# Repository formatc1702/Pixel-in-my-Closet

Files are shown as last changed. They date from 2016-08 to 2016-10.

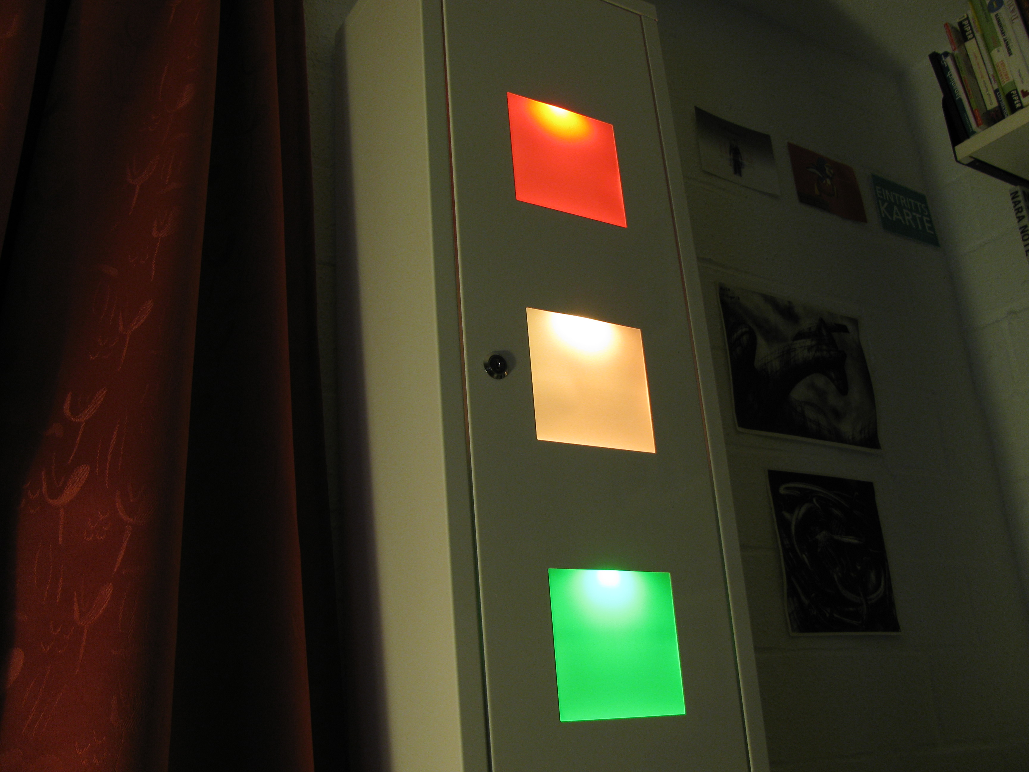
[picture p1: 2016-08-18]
Docs/Photos/IMG_2092.JPG

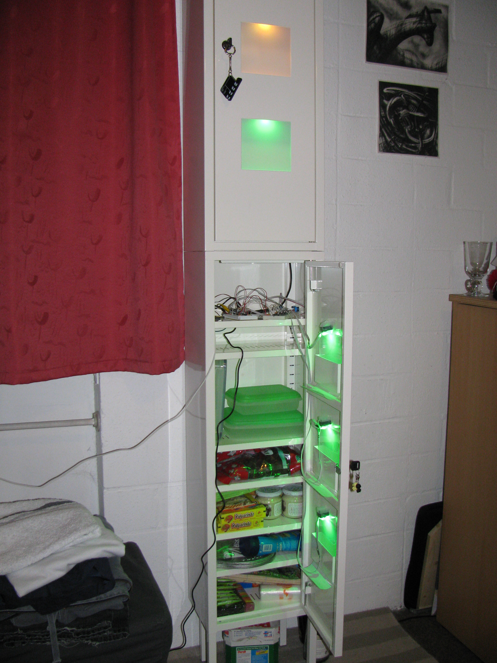
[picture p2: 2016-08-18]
Docs/Photos/IMG_2070.JPG

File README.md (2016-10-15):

#Pixel in my Closet v1

##Description
Music + Arduino + IKEA.
Using six 3W RGB LEDs inside an IKEA PS CD cabinet to light up in reaction to the music attached through a 3.5mm stereo cable. It is combined with the receiver of an old iPod RF remote used to change visualizations and color schemes.
See the YouTube video [here](https://www.youtube.com/watch?v=BKGa15BCBik).

##Directory structure
- **Arduino** contains the firmware. It is a quick&dirty hack and has not been cleaned up.
- **EAGLE** contains the schematic and PCB design files for the project.

##Where to get parts
- [The 3W RGB LED](http://www.dx.com/p/3w-led-emitter-on-star-multicolored-rgb-4530)

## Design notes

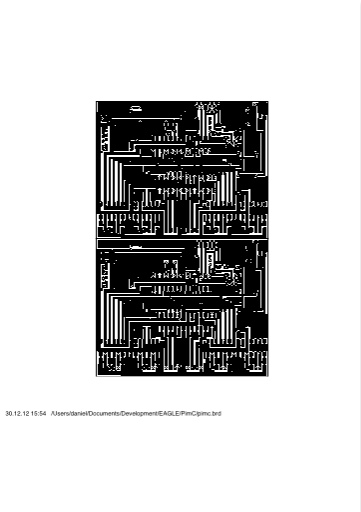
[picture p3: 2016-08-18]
Schematics/PimC_Final/PCB2X.pages/QuickLook/Thumbnail.jpg

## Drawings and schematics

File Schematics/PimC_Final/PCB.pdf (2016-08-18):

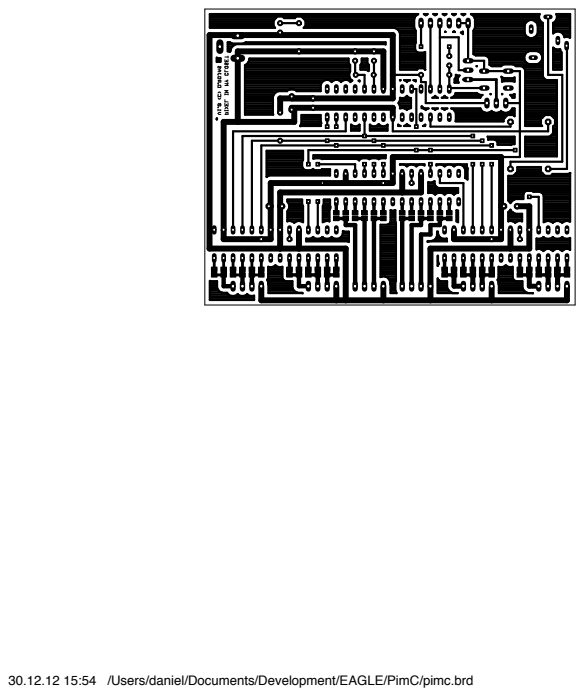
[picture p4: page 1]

30.12.12 15:54 /Users/daniel/Documents/Development/EAGLE/PimC/pimc.brd

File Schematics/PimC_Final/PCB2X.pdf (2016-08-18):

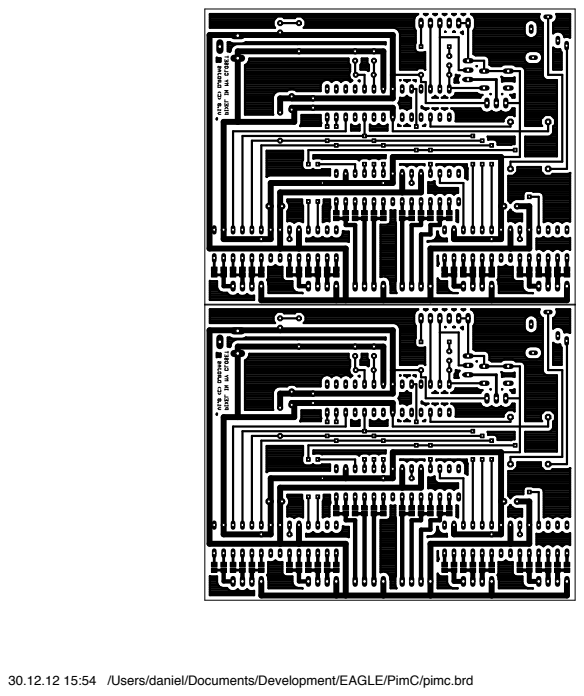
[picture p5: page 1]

30.12.12 15:54 /Users/daniel/Documents/Development/EAGLE/PimC/pimc.brd

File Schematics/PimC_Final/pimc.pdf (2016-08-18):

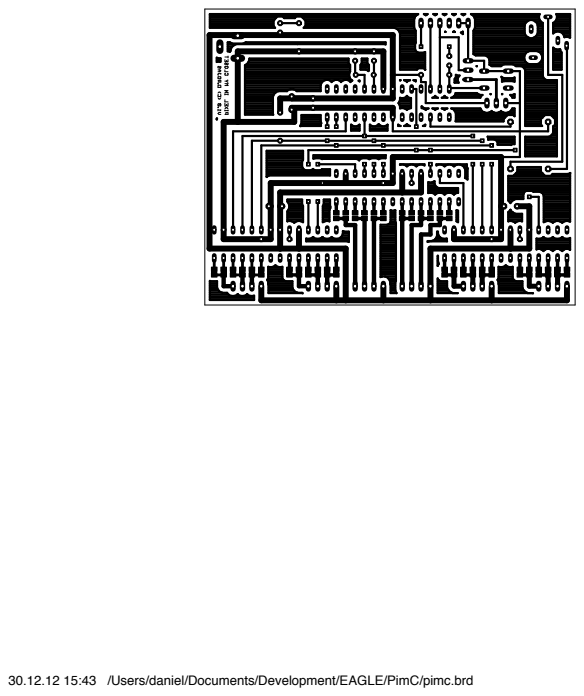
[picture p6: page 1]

30.12.12 15:43 /Users/daniel/Documents/Development/EAGLE/PimC/pimc.brd

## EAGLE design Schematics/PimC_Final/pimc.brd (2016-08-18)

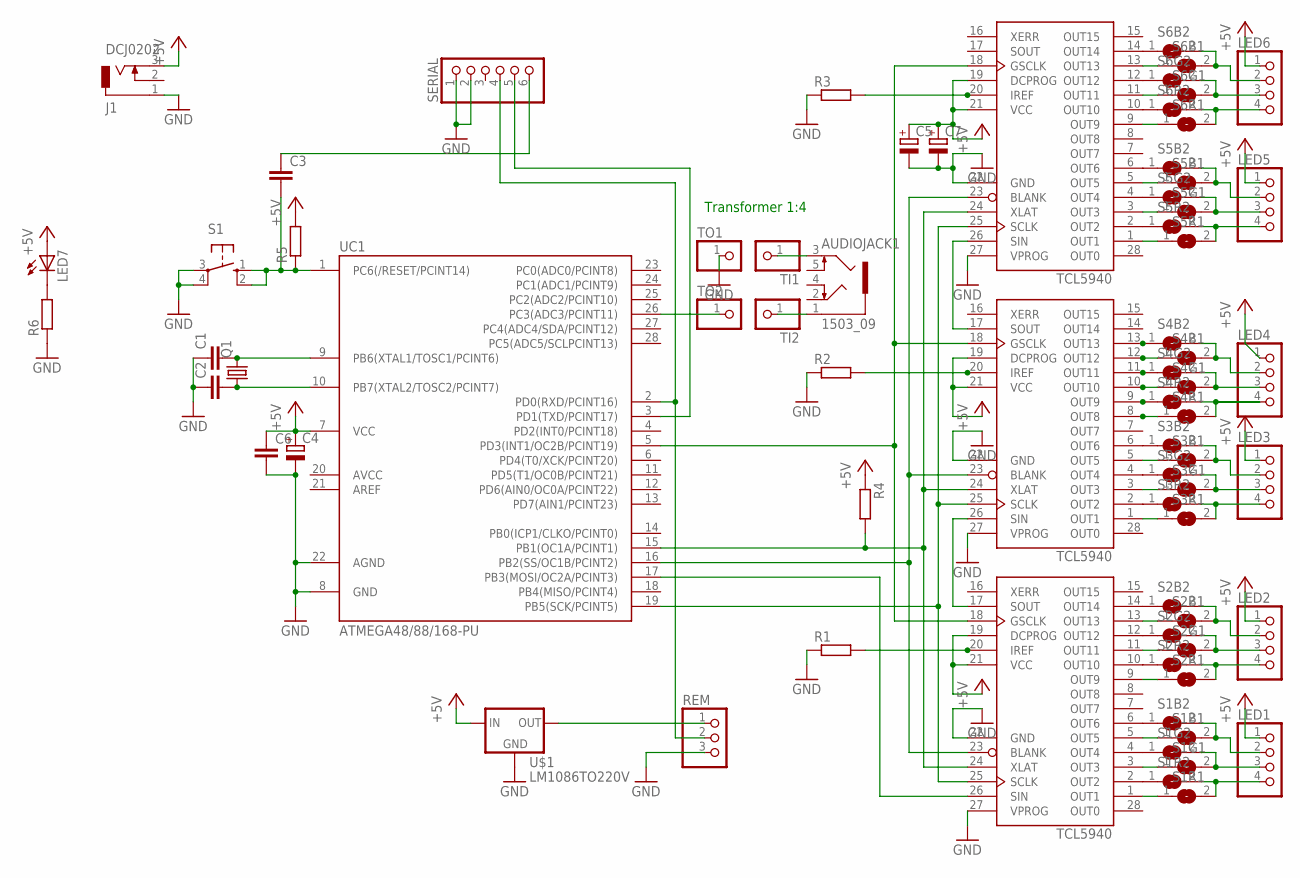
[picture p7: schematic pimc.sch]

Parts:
AUDIOJACK1: 1503_09
C1, C2, C3, C6: C-EU025-025X050; C025-025X050
C4, C5, C7: CPOL-EUE3.5-8; E3,5-8
DRV1, DRV2, DRV3: TCL5940; DIP28
J1: DCJ0202
LED1, LED2, LED3, LED4, LED5, LED6: PINHD-1X4; 1X04
LED7: LED5MM
Q1: CRYSTALHC49S; HC49/S
R1, R2, R3, R4, R5, R6: R-EU_0204/7; 0204/7
REM: PINHD-1X3; 1X03
S1: 10-XX; B3F-10XX
S1B1, S1B2, S1G1, S1G2, S1R1, S1R2, S2B1, S2B2, S2G1, S2G2, S2R1, S2R2, S3B1, S3B2, S3G1, S3G2, S3R1, S3R2, S4B1, S4B2, S4G1, S4G2, S4R1, S4R2, S5B1, S5B2, S5G1, S5G2, S5R1, S5R2, S6B1, S6B2, S6G1, S6G2, S6R1, S6R2: SJ
SERIAL: PINHD-1X6; 1X06
TI1, TI2: PINHD-1X1; 1X01
TO1, TO2: PINHD-1X1; 1X01
U$1: LM1086TO220V; TO220S
UC1: ATMEGA48/88/168-PU; DIL28-3

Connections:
+5V: C4.+, C5.+, C6.1, C7.+, DRV1.19 (DCPROG), DRV1.21 (VCC), DRV2.19 (DCPROG), DRV2.21 (VCC), DRV3.19 (DCPROG), DRV3.21 (VCC), J1.3, LED1.1, LED2.1, LED3.1, LED4.1, LED5.1, LED6.1, LED7.A, R4.1, R5.2, U$1.3 (IN), UC1.7 (VCC)
GND: C1.1, C2.1, C4.-, C5.-, C6.2, C7.-, DRV1.22 (GND), DRV1.27 (VPROG), DRV2.22 (GND), DRV2.27 (VPROG), DRV3.22 (GND), DRV3.27 (VPROG), J1.1, R1.1, R2.1, R3.1, R6.1, REM.3, S1.3, S1.4 (P1), SERIAL.1, SERIAL.2, TO1.1, U$1.1 (GND), UC1.8 (GND), UC1.22 (AGND)
unnamed: DRV1.14 (OUT14), S2B2.1
unnamed: DRV1.12 (OUT12), S2G2.1
unnamed: DRV1.10 (OUT10), S2R2.1
unnamed: DRV1.2 (OUT2), S1R2.1
unnamed: DRV1.4 (OUT4), S1G2.1
unnamed: DRV1.6 (OUT6), S1B2.1
unnamed: DRV1.13 (OUT13), S2B1.1
unnamed: DRV1.11 (OUT11), S2G1.1
unnamed: DRV1.9 (OUT9), S2R1.1
unnamed: DRV1.5 (OUT5), S1B1.1
unnamed: DRV1.3 (OUT3), S1G1.1
unnamed: DRV1.1 (OUT1), S1R1.1
unnamed: LED2.2, S2B1.2, S2B2.2
unnamed: LED2.3, S2G1.2, S2G2.2
unnamed: LED2.4, S2R1.2, S2R2.2
unnamed: LED1.2, S1B1.2, S1B2.2
unnamed: LED1.3, S1G1.2, S1G2.2
unnamed: LED1.4, S1R1.2, S1R2.2
unnamed: DRV2.8 (OUT8), S4R1.1
unnamed: DRV2.10 (OUT10), S4G1.1
unnamed: DRV2.12 (OUT12), S4B1.1
unnamed: DRV2.5 (OUT5), S3B1.1
unnamed: DRV2.3 (OUT3), S3G1.1
unnamed: DRV2.1 (OUT1), S3R1.1
unnamed: LED4.4, S4R1.2, S4R2.2
unnamed: LED4.3, S4G1.2, S4G2.2
unnamed: LED4.2, S4B1.2, S4B2.2
unnamed: LED3.2, S3B1.2, S3B2.2
unnamed: LED3.3, S3G1.2, S3G2.2
unnamed: LED3.4, S3R1.2, S3R2.2
unnamed: DRV2.9 (OUT9), S4R2.1
unnamed: DRV2.11 (OUT11), S4G2.1
unnamed: DRV2.13 (OUT13), S4B2.1
unnamed: DRV2.2 (OUT2), S3R2.1
unnamed: DRV2.4 (OUT4), S3G2.1
unnamed: DRV2.6 (OUT6), S3B2.1
unnamed: DRV3.13 (OUT13), S6B1.1
unnamed: DRV3.11 (OUT11), S6G1.1
unnamed: DRV3.9 (OUT9), S6R1.1
unnamed: DRV3.5 (OUT5), S5B1.1
unnamed: DRV3.3 (OUT3), S5G1.1
unnamed: DRV3.1 (OUT1), S5R1.1
unnamed: LED6.2, S6B1.2, S6B2.2
unnamed: LED6.3, S6G1.2, S6G2.2
unnamed: LED6.4, S6R1.2, S6R2.2
unnamed: LED5.2, S5B1.2, S5B2.2
unnamed: LED5.3, S5G1.2, S5G2.2
unnamed: LED5.4, S5R1.2, S5R2.2
unnamed: DRV3.14 (OUT14), S6B2.1
unnamed: DRV3.12 (OUT12), S6G2.1
unnamed: DRV3.10 (OUT10), S6R2.1
unnamed: DRV3.2 (OUT2), S5R2.1
unnamed: DRV3.4 (OUT4), S5G2.1
unnamed: DRV3.6 (OUT6), S5B2.1
unnamed: DRV1.17 (SOUT), DRV2.26 (SIN)
unnamed: DRV2.17 (SOUT), DRV3.26 (SIN)
unnamed: DRV1.26 (SIN), UC1.17 (PB3(MOSI/OC2A/PCINT3))
unnamed: DRV1.25 (SCLK), DRV2.25 (SCLK), DRV3.25 (SCLK), UC1.19 (PB5(SCK/PCINT5))
unnamed: DRV1.24 (XLAT), DRV2.24 (XLAT), DRV3.24 (XLAT), R4.2, UC1.15 (PB1(OC1A/PCINT1))
unnamed: DRV1.23 (BLANK), DRV2.23 (BLANK), DRV3.23 (BLANK), UC1.16 (PB2(SS/OC1B/PCINT2))
unnamed: DRV3.20 (IREF), R3.2
unnamed: DRV2.20 (IREF), R2.2
unnamed: DRV1.20 (IREF), R1.2
unnamed: DRV1.18 (GSCLK), DRV2.18 (GSCLK), DRV3.18 (GSCLK), UC1.5 (PD3(INT1/OC2B/PCINT19))
unnamed: C1.2, Q1.2, UC1.9 (PB6(XTAL1/TOSC1/PCINT6))
unnamed: C2.2, Q1.1, UC1.10 (PB7(XTAL2/TOSC2/PCINT7))
unnamed: AUDIOJACK1.1, TI2.1
unnamed: AUDIOJACK1.3, TI1.1
unnamed: LED7.K (C), R6.2
unnamed: REM.2, SERIAL.4, UC1.2 (PD0(RXD/PCINT16))
unnamed: SERIAL.5, UC1.3 (PD1(TXD/PCINT17))
unnamed: C3.2, R5.1, S1.1 (S), S1.2 (S1), UC1.1 (PC6(/RESET/PCINT14))
unnamed: C3.1, SERIAL.6
unnamed: REM.1, U$1.2 (OUT)
unnamed: TO2.1, UC1.26 (PC3(ADC3/PCINT11))

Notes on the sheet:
Transformer 1:4

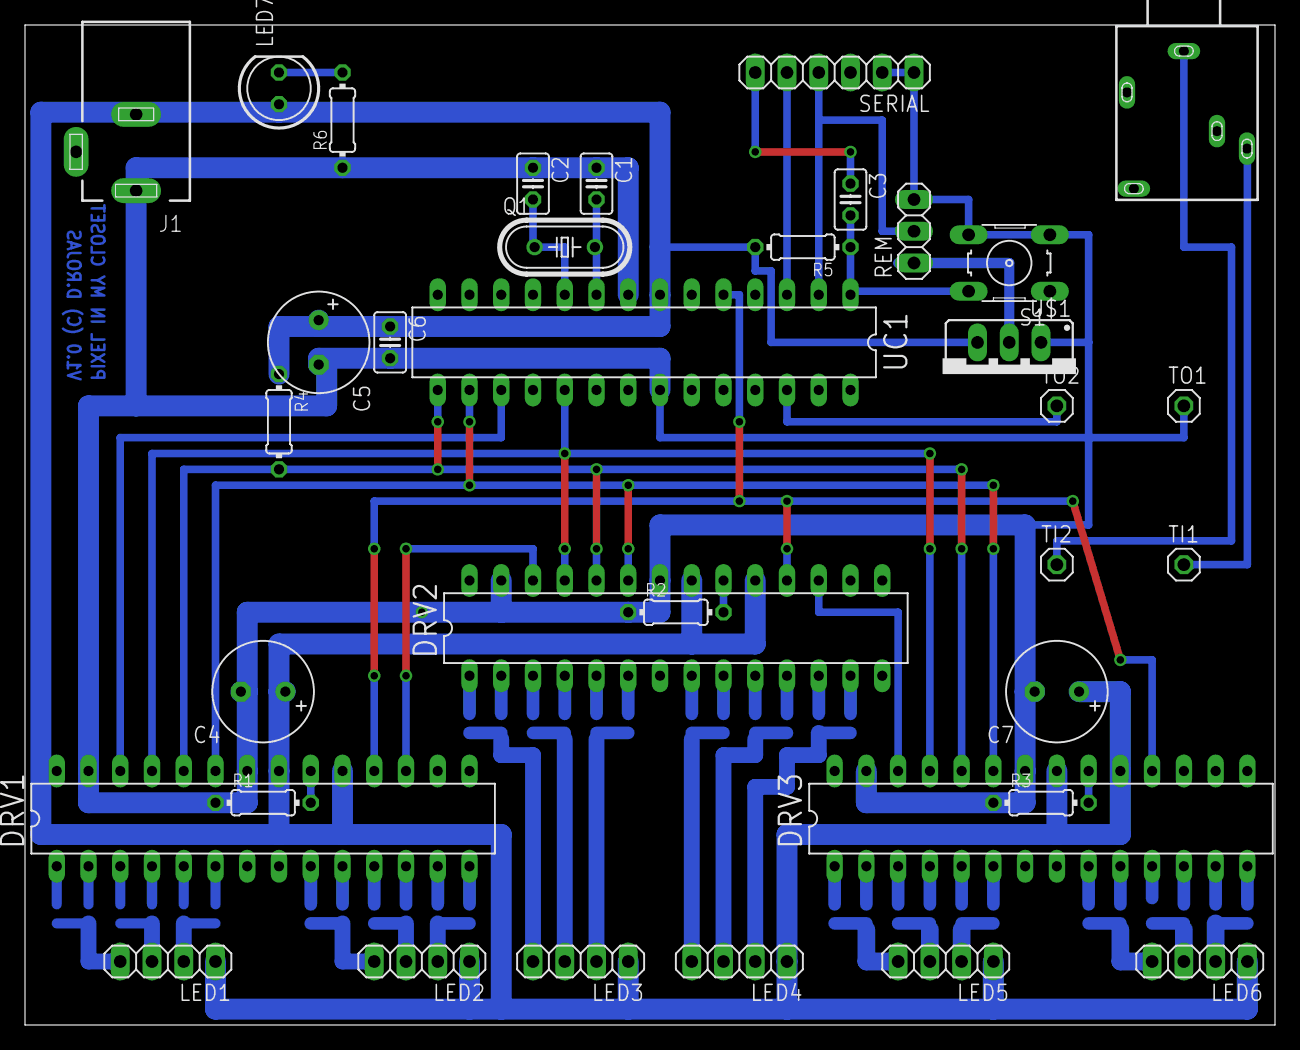
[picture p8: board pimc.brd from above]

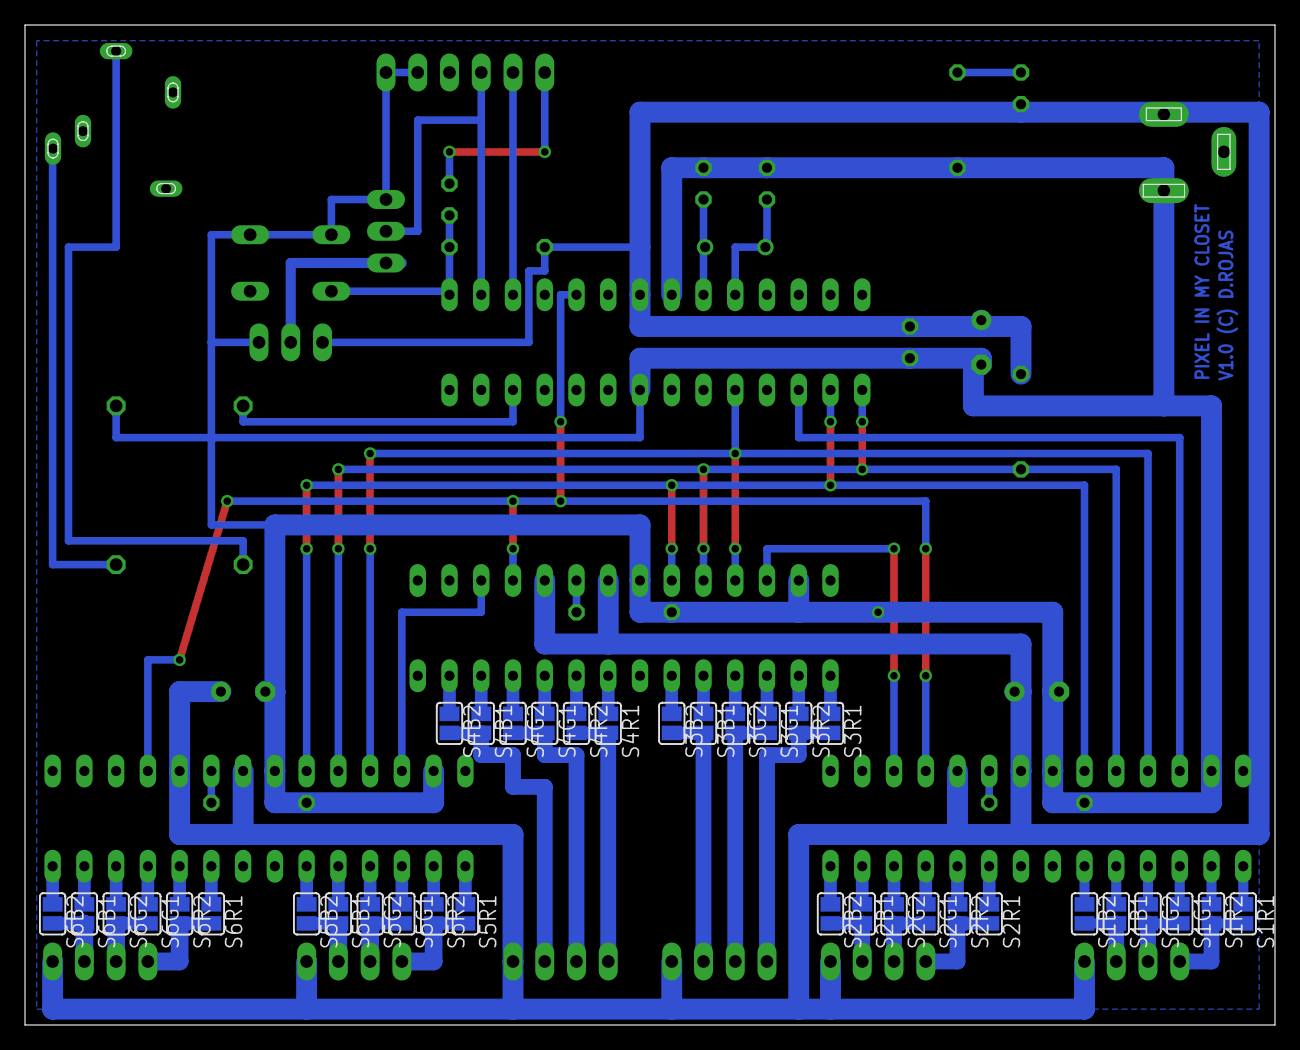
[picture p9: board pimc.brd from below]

Board: 2 copper layers, 100.0 x 80.0 mm, 71 parts (36 on the bottom side), 77 nets.

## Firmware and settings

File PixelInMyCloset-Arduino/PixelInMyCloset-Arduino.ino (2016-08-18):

#include <Wire.h>
#include "lib/Tlc5940/Tlc5940.h"
//#define max6955 B1100000
//#define max6956 B1000000

// MODE STUFF ***********************************************************

int CurrentMode=0;
int CurrentTheme=4;
long NewModeTimer=0;
boolean PoweredOn=true;

// GENERAL STUFF ******************************************************
int i;
long writemil=0;

// PIXEL STUFF ********************************************************

struct Pixel {
  byte red;
  byte green;
  byte blue;
};
struct Pixel BlackPixel={
  0,0,0};
struct Pixel RedPixel={
  255,0,0};
struct Pixel GreenPixel={
  0,255,0};
struct Pixel BluePixel={
  0,0,255};
struct Pixel YellowPixel={
  255,255,0};
struct Pixel CyanPixel={
  0,255,255};
struct Pixel MagentaPixel={
  255,0,255};
struct Pixel WhitePixel={
  255,255,255};
struct Pixel GreyPixel={
  128,128,128
};
struct Pixel OrangePixel={
  255,128,0};

struct PixelStream {
  struct Pixel pixels[6];
};
struct PixelStream BlackPixelStream={
  BlackPixel,BlackPixel,BlackPixel,BlackPixel,BlackPixel,BlackPixel};
struct PixelStream WhitePixelStream={
  WhitePixel,WhitePixel,WhitePixel,WhitePixel,WhitePixel,WhitePixel};

PixelStream toSend={
  0,0,0,0,0,0,0,0,0,0,0,0,0,0,0,0,0,0};
// REMOTE STUFF *********************************************************

#define RemoteREV  0x10
#define RemoteFWD  0x08
#define RemotePLAY 0x01
#define RemoteVDN  0x04
#define RemoteVUP  0x02

byte RemoteLastCommand=0x00;
boolean gotRemote=false;

// MODE 0 - Audiostuff***************************************************
int audioinputpin=3;

// Statuses
long cur=0;
int avgmax=0;
long smooth=0;
long expo=0;
int topbar=0;
int ledcount=0;
int dim;
byte maxbr=0;

// Cycle stuff
boolean cyclecolors=true;
int curcyclecolor=0;
int curcyclecolortemp1=0;
int curcyclecolortemp2=0;
int cyclered=0;
int cyclegreen=0;
int cycleblue=0;
long cycleinterval=16;
long lightfade=56;
long strongfade=170;

// Blip stuff
int curblipnumber=0;
byte curblipbrightness=0;
int curblipdir=0;
boolean curblipchange=false;
int blipcount=1;
int bliparray[]={
  0,0,0,0,0,0};
struct Pixel curblipcolor=BlackPixel;

// Timers
long smoothmil=0;
long ledmil=0;
long maxavgmil=0;
long topbarmil=0;
long cyclemil=0;
long maxbrmil=0;

int curmaxcounter=0;
int maxes[]={
  0,0,0,0,0,0,0,0,0,0};
//int tempmax=0;

// COLOR THEMES ******************************************************* 

struct PixelStream VUThemes[]={ // do not edit existing ones, only add new ones at the end
  {
    GreenPixel,GreenPixel,GreenPixel,GreenPixel,OrangePixel,RedPixel
  }
  ,
  {
    BluePixel,CyanPixel,GreenPixel,YellowPixel,RedPixel,MagentaPixel
  }
  ,
  { // WHY U NO WORK???
    GreenPixel,
    {
      64, 204,0    }
    ,
    {
      128,153,0    }
    ,
    {
      192,102,0    }
    ,
    {
      255,51, 0    }
    ,
    RedPixel
  }
  ,
  BlackPixelStream // all same

  ,
  BlackPixelStream // light fade
  ,
  BlackPixelStream // strong fade
  ,
  WhitePixelStream
};



/////////////////////////////////////////////////////////////////////

void setup()
{
  Tlc.init();
  delay(500);
  //randomSeed(millis());
  //  WireSetup_MAX6956_4bit();
  Serial.begin(19200);
  toSend=WhitePixelStream;
  WriteColors();
  delay(500);
  toSend=BlackPixelStream;
  WriteColors();
}

void loop()
{
  byte RemoteCommand=GetRemote();
  switch(RemoteCommand) {
  case RemotePLAY: 
    PoweredOn=!PoweredOn;
    //    if(!PoweredOn) {
    //      toSend=BlackPixelStream;
    //      WriteColors();
    //      delay(1000);
    //    }
    break;
  case RemoteFWD: 
    if(++CurrentMode>=6)
      CurrentMode=0;
    //    NewModeTimer=millis();
    maxbr=0;
    break;
  case RemoteREV: 
    if(--CurrentMode<0)
      CurrentMode=5;
    //    NewModeTimer=millis();
    maxbr=0;
    break;
  case RemoteVUP:
    switch(CurrentMode) {
    case 0:
    case 3:
    case 4:
    case 5:
      if(++CurrentTheme>=sizeof(VUThemes)/18)
        CurrentTheme=0;
      break;
    case 1:
      cyclecolors=!cyclecolors;
      break;
    case 2:
      if(cycleinterval>1)
        cycleinterval/=2;
      break;


      break;
    }
    break;
  case RemoteVDN:
    switch(CurrentMode) {
    case 0:
    case 3:
    case 4:
    case 5:
      if(--CurrentTheme<0)
        CurrentTheme=sizeof(VUThemes)/18-1;
      break;
    case 1:
      cyclecolors=!cyclecolors;
      break;
    case 2:
      cycleinterval*=2;
      break;

      break;
    }
    break;
  }

  if(millis()-NewModeTimer<=100) {
    toSend=BlackPixelStream;
    toSend.pixels[CurrentMode]=WhitePixel;
  } 

  else {
    if(cyclecolors) ColorCycle(); 
    switch(CurrentMode) {
    case 0:
      mode0();
      break;
    case 1: 
      mode1();
      break;
    case 2: 
      mode2();
      break;
    case 3: 
      mode3();
      break;
    case 4: 
      mode4();
      break;
    case 5: 
      mode5();
      break;
    }
  }

  //  if(PoweredOn && millis()-writemil>50) {
  if(millis()-writemil>50) {
    WriteColors();
    writemil=millis();
  }

  if(millis()-maxbrmil>1) {
    if(PoweredOn) {
      if(maxbr<128)
        maxbr++;
    } 
    else {
      if(maxbr>0)
        maxbr-=2;
    }
    maxbrmil=millis();
  }
}

void h2rgb(float H, int& R, int& G, int& B) {

  H/=1024;
  int var_i;
  float S=1, V=1, var_1, var_2, var_3, var_h, var_r, var_g, var_b;

  if ( S == 0 )                       //HSV values = 0 ÷ 1
  {
    R = V * 255;
    G = V * 255;
    B = V * 255;
  }
  else
  {
    var_h = H * 6;
    if ( var_h == 6 ) var_h = 0;      //H must be < 1
    var_i = int( var_h ) ;            //Or ... var_i = floor( var_h )
    var_1 = V * ( 1 - S );
    var_2 = V * ( 1 - S * ( var_h - var_i ) );
    var_3 = V * ( 1 - S * ( 1 - ( var_h - var_i ) ) );

    if      ( var_i == 0 ) {
      var_r = V     ;
      var_g = var_3 ;
      var_b = var_1 ;
    }
    else if ( var_i == 1 ) {
      var_r = var_2 ;
      var_g = V     ;
      var_b = var_1 ;
    }
    else if ( var_i == 2 ) {
      var_r = var_1 ;
      var_g = V     ;
      var_b = var_3 ;
    }
    else if ( var_i == 3 ) {
      var_r = var_1 ;
      var_g = var_2 ;
      var_b = V     ;
    }
    else if ( var_i == 4 ) {
      var_r = var_3 ;
      var_g = var_1 ;
      var_b = V     ;
    }
    else                   {
      var_r = V     ;
      var_g = var_1 ;
      var_b = var_2 ;
    }

    R = (1-var_r) * 255;                  //RGB results = 0 ÷ 255
    G = (1-var_g) * 255;
    B = (1-var_b) * 255;
  }
}

void ColorCycle() {
  // CYCLE MODE

  /*
  if(millis()-cyclemil>5000) {
   Pixel temp=VUThemes[1].pixels[5];
   for(i=5;i>=1;i--) {
   VUThemes[1].pixels[i]=VUThemes[1].pixels[i-1];
   }
   VUThemes[1].pixels[0]=temp;
   cyclemil=millis();
   }
   // */
  ///*
  if(millis()-cyclemil>cycleinterval&&CurrentMode!=4) {
    if(++curcyclecolor>=1024)
      curcyclecolor-=1024;
    curcyclecolortemp1=curcyclecolor;
    curcyclecolortemp2=curcyclecolor;
    //    for(i=0;i<=5;i++) {
    for(i=5;i>=0;i--) {
      if(curcyclecolortemp1>=1024)
        curcyclecolortemp1-=1024;
      if(curcyclecolortemp2>=1024)
        curcyclecolortemp2-=1024;
      h2rgb(curcyclecolortemp1,cyclered,cyclegreen,cycleblue);
      cyclered=(int)((long)(cyclered*cyclered/255));
      cyclegreen=(int)((long)(cyclegreen*cyclegreen/255));
      cycleblue=(int)((long)(cycleblue*cycleblue/255));
      VUThemes[4].pixels[i].red=cyclered;
      VUThemes[4].pixels[i].green=cyclegreen;
      VUThemes[4].pixels[i].blue=cycleblue;
      h2rgb(curcyclecolortemp2,cyclered,cyclegreen,cycleblue);
      cyclered=(int)((long)(cyclered*cyclered/255));
      cyclegreen=(int)((long)(cyclegreen*cyclegreen/255));
      cycleblue=(int)((long)(cycleblue*cycleblue/255));
      VUThemes[5].pixels[i].red=cyclered;
      VUThemes[5].pixels[i].green=cyclegreen;
      VUThemes[5].pixels[i].blue=cycleblue;
      VUThemes[3].pixels[i]=VUThemes[4].pixels[0];
      curcyclecolortemp1+= lightfade; //50; //analogRead(0); //50;
      curcyclecolortemp2+= strongfade; //50; //analogRead(0); //50;
    }
    cyclemil=millis();
  }
  // */
}

void WriteColors() {
  //WriteColors_MAX6956_4bit();
  WriteColors_TLC5941();
}  

struct Pixel testfkt() {
  struct Pixel bla={
    0,0,0
  };
  return  bla;
}

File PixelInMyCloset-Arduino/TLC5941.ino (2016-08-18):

void WriteColors_TLC5941() {
  Tlc.clear();
  
  Tlc.set(5,maxbr*(int)toSend.pixels[0].red/8);
  Tlc.set(3,maxbr*(int)toSend.pixels[0].green/8);
  Tlc.set(1,maxbr*(int)toSend.pixels[0].blue/8);

  Tlc.set(13,maxbr*(int)toSend.pixels[1].red/8);
  Tlc.set(11,maxbr*(int)toSend.pixels[1].green/8);
  Tlc.set(9,maxbr*(int)toSend.pixels[1].blue/8);

  Tlc.set(21,maxbr*(int)toSend.pixels[2].red/8);
  Tlc.set(19,maxbr*(int)toSend.pixels[2].green/8);
  Tlc.set(17,maxbr*(int)toSend.pixels[2].blue/8);

  Tlc.set(28,maxbr*(int)toSend.pixels[3].red/8);
  Tlc.set(26,maxbr*(int)toSend.pixels[3].green/8);
  Tlc.set(24,maxbr*(int)toSend.pixels[3].blue/8);

  Tlc.set(37,maxbr*(int)toSend.pixels[4].red/8);
  Tlc.set(35,maxbr*(int)toSend.pixels[4].green/8);
  Tlc.set(33,maxbr*(int)toSend.pixels[4].blue/8);

  Tlc.set(45,maxbr*(int)toSend.pixels[5].red/8);
  Tlc.set(43,maxbr*(int)toSend.pixels[5].green/8);
  Tlc.set(41,maxbr*(int)toSend.pixels[5].blue/8);
  
  Tlc.update();
  
//  Serial.println(toSend.pixels[0].red,DEC);
//  Serial.println(dim*toSend.pixels[0].red,DEC);
//  Serial.println(dim,DEC);
//  Serial.println();
} 
